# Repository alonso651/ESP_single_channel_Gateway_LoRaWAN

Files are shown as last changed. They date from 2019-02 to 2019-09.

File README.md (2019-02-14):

Gateway LoRaWAN ESP8266 de un solo canal
========================================
Febrero de 2019 

Single Channel Gateway LoRaWAN
------------------------------
Es un Gateway LoRaWAN de un único canal.

Cuenta con dos modos de funcionamiento:
1. Normal: Un solo canal (0-7) y un SF (SF7-SF12).
2. CAD: Un solo canal (0-7) y todos los SF de SF7 a SF12 (Más versátil).

En la configuración actual se utilizó la primer sub banda (sub banda 1) de la banda 
de frecuencias ISM US915 MHz. 

Sub banda 1 (903.9 - 905.3 MHz): 

	· Canal 0 - 903.9 MHz
	· Canal 1 - 904.1 MHz
	· Canal 2 - 904.3 MHz
	· Canal 3 - 904.5 MHz
	· Canal 4 - 904.7 MHz
	· Canal 5 - 904.9 MHz
	· Canal 6 - 905.1 MHz
	· Canal 7 - 905.3 MHz

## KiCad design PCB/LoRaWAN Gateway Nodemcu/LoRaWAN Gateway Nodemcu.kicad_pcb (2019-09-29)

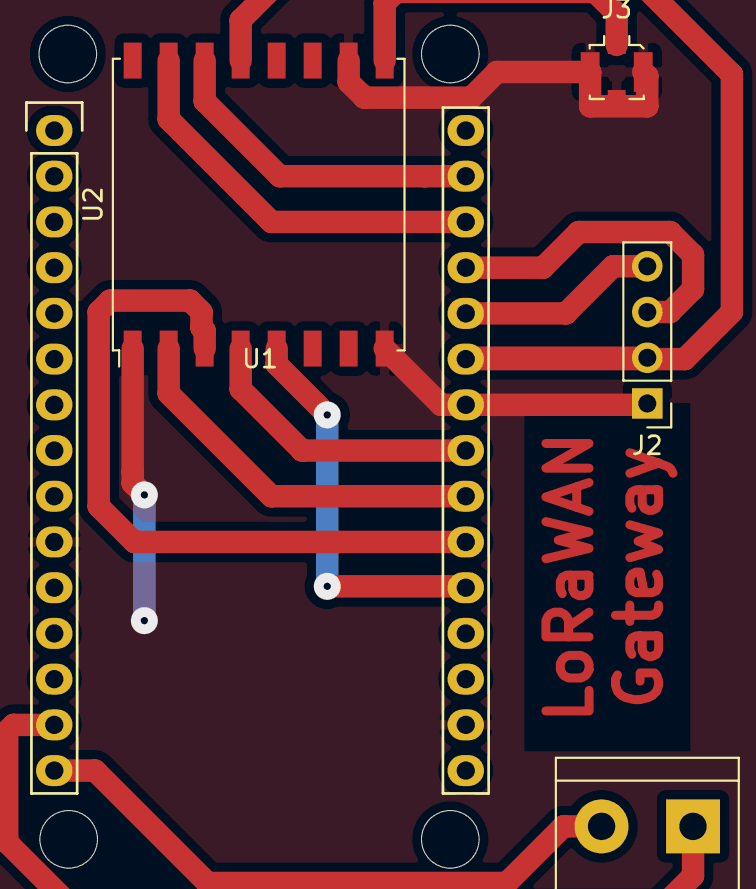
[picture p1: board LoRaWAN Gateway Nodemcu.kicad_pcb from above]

Board: 2 copper layers, 5 parts (0 on the bottom side), 13 nets.

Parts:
J1: 5V in; TerminalBlock_bornier-2_P5.08mm
J2: Display Oled I2C; PinHeader_1x04_P2.54mm_Vertical
J3: Antena; U.FL_Molex_MCRF_73412-0110_Vertical
U1: NodeMCU Amica R2; NodeMCU_Amica_R2
U2: RFM95W; HOPERF_RFM9XW_SMD

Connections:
/3v3: J2.2, U1.11, U1.16, U1.25, U2.13
/ANT: J3.1, U2.9
/DIO0: U1.29, U2.14
/DIO1: U1.28, U2.15
/GND: J2.1, J3.2, U1.10, U1.17, U1.24, U2.1, U2.8, U2.10
/GNDin: J1.1, U1.14
/MISO: U1.22, U2.2
/MOSI: U1.21, U2.3
/NSS: U1.20, U2.5
/SCK: U1.23, U2.4
/SCL: J2.3, U1.27
/SDA: J2.4, U1.26
/Vin: J1.2, U1.15

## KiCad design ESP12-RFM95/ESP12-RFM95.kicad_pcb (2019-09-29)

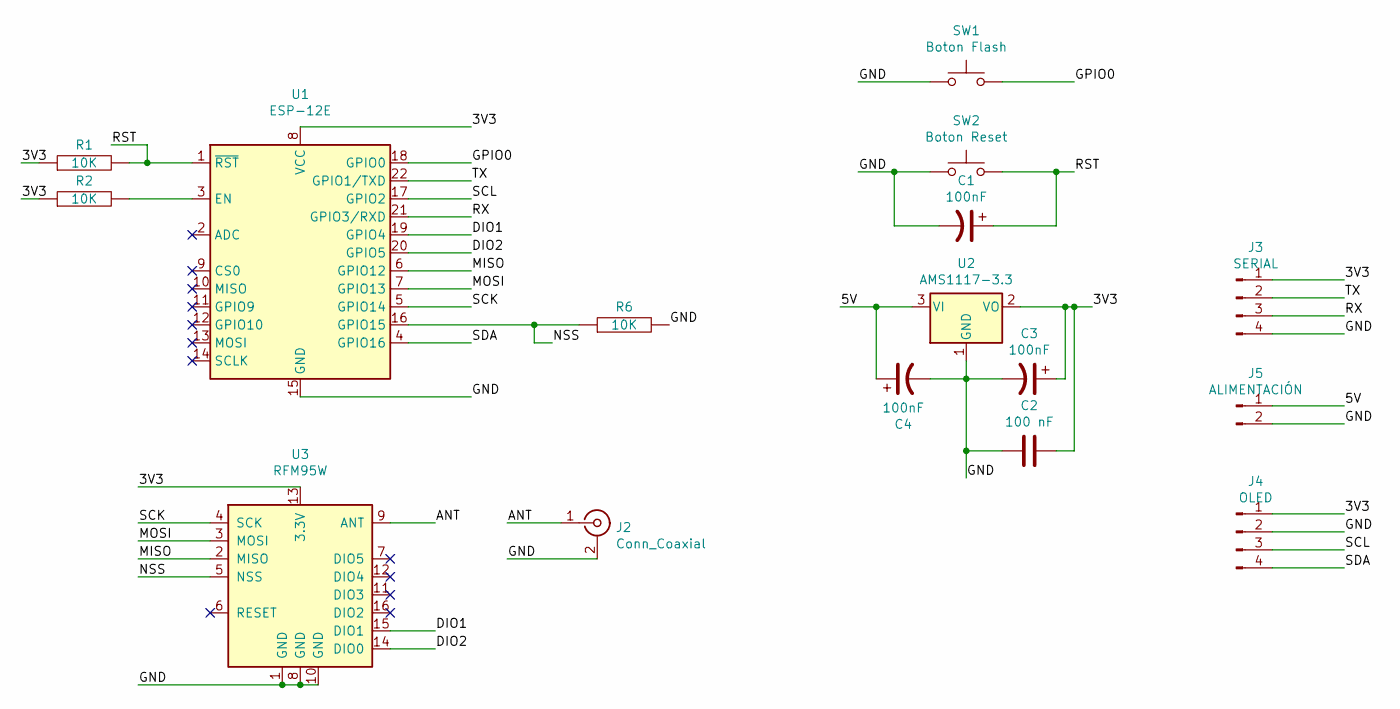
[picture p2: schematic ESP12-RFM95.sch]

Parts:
C1, C3, C4: 100nF; CP_Radial_D5.0mm_P2.50mm
C2: 100 nF; C_Disc_D3.0mm_W2.0mm_P2.50mm
J2: Conn_Coaxial; SMA_Amphenol_901-144_Vertical
J3: SERIAL; PinHeader_1x04_P2.54mm_Horizontal
J4: OLED; I2C_SSD1306
J5: ALIMENTACIÓN; PinHeader_1x02_P2.54mm_Vertical
R1, R2, R6: 10K; R_Axial_DIN0207_L6.3mm_D2.5mm_P5.08mm_Vertical
SW1: Boton Flash; SW_DIP_SPSTx01_Slide_6.7x4.1mm_W6.73mm_P2.54mm_LowProfile_J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
SW2: Boton Reset; SW_DIP_SPSTx01_Slide_6.7x4.1mm_W6.73mm_P2.54mm_LowProfile_J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
U1: ESP-12E; ESP-12E_2
U2: AMS1117-3.3; SOT-223-3_TabPin2
U3: RFM95W; HOPERF_RFM9XW_SMD

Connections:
/3V3: C2.1, C3.1, J3.1, J4.1, R1.1, R2.1, U1.8 (VCC), U2.2 (VO), U3.13 (3.3V); also elsewhere on the board
/5V: C4.1, J5.1, U2.3 (VI)
/ANT: J2.1 (In), U3.9 (ANT)
/DIO1: U1.19 (GPIO4), U3.15 (DIO1)
/DIO2: U1.20 (GPIO5), U3.14 (DIO0)
/GND: C1.2, C2.2, C3.2, C4.2, J2.2 (Ext), J3.4, J4.2, J5.2, R6.2, SW1.1, SW2.1, U1.15 (GND), U2.1 (GND), U3.1 (GND), U3.8 (GND), U3.10 (GND); also elsewhere on the board
/GPIO0: SW1.2, U1.18 (GPIO0)
/MISO: U1.6 (GPIO12), U3.2 (MISO)
/MOSI: U1.7 (GPIO13), U3.3 (MOSI)
/NSS: R6.1, U1.16 (GPIO15), U3.5 (NSS)
/RST: C1.1, R1.2, SW2.2, U1.1 (~RST)
/RX: J3.3, U1.21 (GPIO3/RXD)
/SCK: U1.5 (GPIO14), U3.4 (SCK)
/SCL: J4.3, U1.17 (GPIO2); also elsewhere on the board
/SDA: J4.4, U1.4 (GPIO16); also elsewhere on the board
/TX: J3.2, U1.22 (GPIO1/TXD)
unnamed: R2.2, U1.3 (EN)

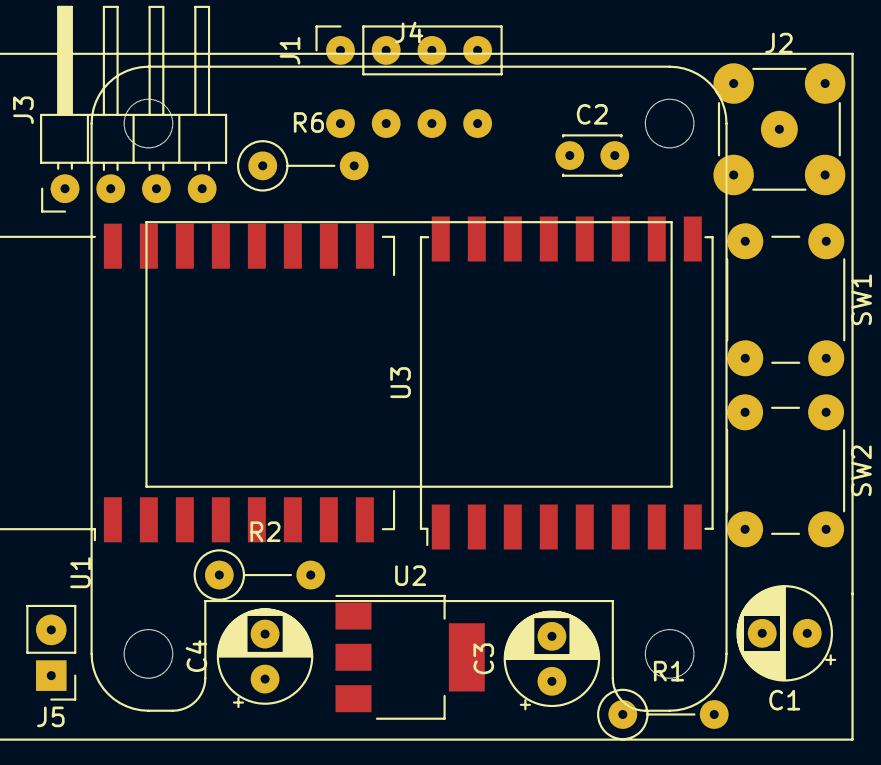
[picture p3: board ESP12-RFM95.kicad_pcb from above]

Board: 2 copper layers, 17 parts (0 on the bottom side), 17 nets.

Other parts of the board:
J1: I2C; PinSocket_1x04_P2.54mm_Vertical

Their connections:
/3V3: J1.1; also elsewhere on the board
/GND: J1.2; also elsewhere on the board
/SCL: J1.3; also elsewhere on the board
/SDA: J1.4; also elsewhere on the board

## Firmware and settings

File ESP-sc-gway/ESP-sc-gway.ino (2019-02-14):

// 1-channel LoRa Gateway for ESP8266 jjjjjjjj
// Copyright (c) 2016, 2017, 2018 Maarten Westenberg version for ESP8266
// Version 5.3.3
// Date: 2018-08-25
// Author: Maarten Westenberg (mw12554@hotmail.com)
//
// Based on work done by Thomas Telkamp for Raspberry PI 1-ch gateway and many others.
//
// All rights reserved. This program and the accompanying materials
// are made available under the terms of the MIT License
// which accompanies this distribution, and is available at
// https://opensource.org/licenses/mit-license.php
//
// NO WARRANTY OF ANY KIND IS PROVIDED
//
// The protocols and specifications used for this 1ch gateway: 
// 1. LoRA Specification version V1.0 and V1.1 for Gateway-Node communication
//	
// 2. Semtech Basic communication protocol between Lora gateway and server version 3.0.0
//	https://github.com/Lora-net/packet_forwarder/blob/master/PROTOCOL.TXT
//
// Notes: 
// - Once call gethostbyname() to get IP for services, after that only use IP
//	 addresses (too many gethost name makes the ESP unstable)
// - Only call yield() in main stream (not for background NTP sync). 
//
// ----------------------------------------------------------------------------------------

#include "ESP-sc-gway.h"						// This file contains configuration of GWay

#if defined (ARDUINO_ARCH_ESP32) || defined(ESP32)
#define ESP32_ARCH 1
#endif

#include <Esp.h>								// ESP8266 specific IDE functions
#include <string.h>
#include <stdio.h>
#include <sys/types.h>
#include <unistd.h>
#include <fcntl.h>
#include <cstdlib>
#include <sys/time.h>
#include <cstring>
#include <string>								// C++ specific string functions

#include <SPI.h>								// For the RFM95 bus
#include <TimeLib.h>							// http://playground.arduino.cc/code/time
#include <DNSServer.h>							// Local DNSserver
#include <ArduinoJson.h>
#include <FS.h>									// ESP8266 Specific
#include <WiFiUdp.h>
#include <pins_arduino.h>
#include <gBase64.h>							// https://github.com/adamvr/arduino-base64 (changed the name)

// Local include files
#include "loraModem.h"
#include "loraFiles.h"
#include "sensor.h"
#include "oLED.h"

extern "C" {
#include "lwip/err.h"
#include "lwip/dns.h"
}

#if WIFIMANAGER==1
#include <WiFiManager.h>						// Library for ESP WiFi config through an AP
#endif

#if (GATEWAYNODE==1) || (_LOCALSERVER==1)
#include "AES-128_V10.h"
#endif


// ----------- Specific ESP32 stuff --------------
#if ESP32_ARCH==1								// IF ESP32

#include "WiFi.h"
#include <WiFiClient.h>
#include <ESPmDNS.h>
#include <SPIFFS.h>
#if A_SERVER==1
#include <ESP32WebServer.h>						// Dedicated Webserver for ESP32
#include <Streaming.h>          				// http://arduiniana.org/libraries/streaming/
#endif
#if A_OTA==1
#include <ESP32httpUpdate.h>					// Not yet available
#include <ArduinoOTA.h>
#endif//OTA

// ----------- Generic ESP8266 stuff --------------
#else

#include <ESP8266WiFi.h>						// Which is specific for ESP8266
#include <ESP8266mDNS.h>
extern "C" {
#include "user_interface.h"
#include "c_types.h"
}
#if A_SERVER==1
#include <ESP8266WebServer.h>
#include <Streaming.h>          				// http://arduiniana.org/libraries/streaming/
#endif //A_SERVER
#if A_OTA==1
#include <ESP8266httpUpdate.h>
#include <ArduinoOTA.h>
#endif//OTA

#endif//ESP_ARCH

// ----------- Declaration of vars --------------
uint8_t debug=1;								// Debug level! 0 is no msgs, 1 normal, 2 extensive
uint8_t pdebug=0xFF;							// Allow all atterns (departments)

#if GATEWAYNODE==1
#if _GPS==1
#include <TinyGPS++.h>
TinyGPSPlus gps;
HardwareSerial Serial1(1);
#endif
#endif

// You can switch webserver off if not necessary but probably better to leave it in.
#if A_SERVER==1
#if ESP32_ARCH==1
	ESP32WebServer server(A_SERVERPORT);
#else
	ESP8266WebServer server(A_SERVERPORT);
#endif
#endif
using namespace std;

byte currentMode = 0x81;

bool sx1272 = true;								// Actually we use sx1276/RFM95

uint32_t cp_nb_rx_rcv;							// Number of messages received by gateway
uint32_t cp_nb_rx_ok;							// Number of messages received OK
uint32_t cp_nb_rx_bad;							// Number of messages received bad
uint32_t cp_nb_rx_nocrc;						// Number of messages without CRC
uint32_t cp_up_pkt_fwd;

uint8_t MAC_array[6];

// ----------------------------------------------------------------------------
//
// Configure these values only if necessary!
//
// ----------------------------------------------------------------------------

// Set spreading factor (SF7 - SF12)
sf_t sf 			= _SPREADING;
sf_t sfi 			= _SPREADING;				// Initial value of SF

// Set location, description and other configuration parameters
// Defined in ESP-sc_gway.h
//
float lat			= _LAT;						// Configuration specific info...
float lon			= _LON;
int   alt			= _ALT;
char platform[24]	= _PLATFORM; 				// platform definition
char email[40]		= _EMAIL;    				// used for contact email
char description[64]= _DESCRIPTION;				// used for free form description 

// define servers

IPAddress ntpServer;							// IP address of NTP_TIMESERVER
IPAddress ttnServer;							// IP Address of thethingsnetwork server
IPAddress thingServer;

WiFiUDP Udp;

time_t startTime = 0;							// The time in seconds since 1970 that the server started
												// be aware that UTP time has to succeed for meaningful values.
												// We use this variable since millis() is reset every 50 days...
uint32_t eventTime = 0;							// Timing of _event to change value (or not).
uint32_t sendTime = 0;							// Time that the last message transmitted
uint32_t doneTime = 0;							// Time to expire when CDDONE takes too long
uint32_t statTime = 0;							// last time we sent a stat message to server
uint32_t pulltime = 0;							// last time we sent a pull_data request to server
//uint32_t lastTmst = 0;							// Last activity Timer

#if A_SERVER==1
uint32_t wwwtime = 0;
#endif
#if NTP_INTR==0
uint32_t ntptimer = 0;
#endif

#define TX_BUFF_SIZE  1024						// Upstream buffer to send to MQTT
#define RX_BUFF_SIZE  1024						// Downstream received from MQTT
#define STATUS_SIZE	  512						// Should(!) be enough based on the static text .. was 1024

#if GATEWAYNODE==1
uint16_t frameCount=0;							// We write this to SPIFF file
#endif

// volatile bool inSPI This initial value of mutex is to be free,
// which means that its value is 1 (!)
// 
int mutexSPI = 1;

// ----------------------------------------------------------------------------
// FORWARD DECARATIONS
// These forward declarations are done since other .ino fils are linked by the
// compiler/linker AFTER the main ESP-sc-gway.ino file. 
// And espcesially when calling functions with ICACHE_RAM_ATTR the complier 
// does not want this.
// Solution can also be to pecify less STRICT compile options in Makefile
// ----------------------------------------------------------------------------

void ICACHE_RAM_ATTR Interrupt_0();
void ICACHE_RAM_ATTR Interrupt_1();

int sendPacket(uint8_t *buf, uint8_t length);		// _txRx.ino
void setupWWW();									// _wwwServer.ino
void SerialTime();									// _utils.ino
static void printIP(IPAddress ipa, const char sep, String& response);	// _wwwServer.ino

void init_oLED();									// oLED.ino
void acti_oLED();
void addr_oLED();

void setupOta(char *hostname);
void initLoraModem();								// _loraModem.ino
void cadScanner();
void rxLoraModem();									// _loraModem.ino
void writeRegister(uint8_t addr, uint8_t value);	// _loraModem.ino

void stateMachine();								// _stateMachine.ino

void SerialStat(uint8_t intr);						// _utils.ino

#if MUTEX==1
// Forward declarations
void ICACHE_FLASH_ATTR CreateMutux(int *mutex);
bool ICACHE_FLASH_ATTR GetMutex(int *mutex);
void ICACHE_FLASH_ATTR ReleaseMutex(int *mutex);
#endif

// ----------------------------------------------------------------------------
// DIE is not use actively in the source code anymore.
// It is replaced by a Serial.print command so we know that we have a problem
// somewhere.
// There are at least 3 other ways to restart the ESP. Pick one if you want.
// ----------------------------------------------------------------------------
void die(const char *s)
{
	Serial.println(s);
	if (debug>=2) Serial.flush();

	delay(50);
	// system_restart();						// SDK function
	// ESP.reset();				
	abort();									// Within a second
}

// ----------------------------------------------------------------------------
// gway_failed is a function called by ASSERT in ESP-sc-gway.h
//
// ----------------------------------------------------------------------------
void gway_failed(const char *file, uint16_t line) {
	Serial.print(F("Program failed in file: "));
	Serial.print(file);
	Serial.print(F(", line: "));
	Serial.println(line);
	if (debug>=2) Serial.flush();
}

// ----------------------------------------------------------------------------
// Print leading '0' digits for hours(0) and second(0) when
// printing values less than 10
// ----------------------------------------------------------------------------
void printDigits(unsigned long digits)
{
    // utility function for digital clock display: prints leading 0
    if(digits < 10)
        Serial.print(F("0"));
    Serial.print(digits);
}

// ----------------------------------------------------------------------------
// Print utin8_t values in HEX with leading 0 when necessary
// ----------------------------------------------------------------------------
void printHexDigit(uint8_t digit)
{
    // utility function for printing Hex Values with leading 0
    if(digit < 0x10)
        Serial.print('0');
    Serial.print(digit,HEX);
}


// ----------------------------------------------------------------------------
// Print the current time
// ----------------------------------------------------------------------------
static void printTime() {
	switch (weekday())
	{
		case 1: Serial.print(F("Sunday")); break;
		case 2: Serial.print(F("Monday")); break;
		case 3: Serial.print(F("Tuesday")); break;
		case 4: Serial.print(F("Wednesday")); break;
		case 5: Serial.print(F("Thursday")); break;
		case 6: Serial.print(F("Friday")); break;
		case 7: Serial.print(F("Saturday")); break;
		default: Serial.print(F("ERROR")); break;
	}
	Serial.print(F(" "));
	printDigits(hour());
	Serial.print(F(":"));
	printDigits(minute());
	Serial.print(F(":"));
	printDigits(second());
	return;
}


// ----------------------------------------------------------------------------
// Convert a float to string for printing
// Parameters:
//	f is float value to convert
//	p is precision in decimal digits
//	val is character array for results
// ----------------------------------------------------------------------------
void ftoa(float f, char *val, int p) {
	int j=1;
	int ival, fval;
	char b[7] = { 0x00, 0x00, 0x00, 0x00, 0x00, 0x00, 0x00 };
	
	for (int i=0; i< p; i++) { j= j*10; }

	ival = (int) f;								// Make integer part
	fval = (int) ((f- ival)*j);					// Make fraction. Has same sign as integer part
	if (fval<0) fval = -fval;					// So if it is negative make fraction positive again.
												// sprintf does NOT fit in memory
	if ((f<0) && (ival == 0)) strcat(val, "-");
	strcat(val,itoa(ival,b,10));				// Copy integer part first, base 10, null terminated
	strcat(val,".");							// Copy decimal point
	
	itoa(fval,b,10);							// Copy fraction part base 10
	for (int i=0; i<(p-strlen(b)); i++) {
		strcat(val,"0"); 						// first number of 0 of faction?
	}
	
	// Fraction can be anything from 0 to 10^p , so can have less digits
	strcat(val,b);
}

// ============================================================================
// NTP TIME functions



// ----------------------------------------------------------------------------
// Send the request packet to the NTP server.
//
// ----------------------------------------------------------------------------
int sendNtpRequest(IPAddress timeServerIP) {
	const int NTP_PACKET_SIZE = 48;				// Fixed size of NTP record
	byte packetBuffer[NTP_PACKET_SIZE];

	memset(packetBuffer, 0, NTP_PACKET_SIZE);	// Zeroise the buffer.
	
	packetBuffer[0]  = 0b11100011;   			// LI, Version, Mode
	packetBuffer[1]  = 0;						// Stratum, or type of clock
	packetBuffer[2]  = 6;						// Polling Interval
	packetBuffer[3]  = 0xEC;					// Peer Clock Precision
	// 8 bytes of zero for Root Delay & Root Dispersion
	packetBuffer[12] = 49;
	packetBuffer[13] = 0x4E;
	packetBuffer[14] = 49;
	packetBuffer[15] = 52;	

	
	if (!sendUdp( (IPAddress) timeServerIP, (int) 123, packetBuffer, NTP_PACKET_SIZE)) {
		gwayConfig.ntpErr++;
		gwayConfig.ntpErrTime = now();
		return(0);	
	}
	return(1);
}


// ----------------------------------------------------------------------------
// Get the NTP time from one of the time servers
// Note: As this function is called from SyncINterval in the background
//	make sure we have no blocking calls in this function
// ----------------------------------------------------------------------------
time_t getNtpTime()
{
	gwayConfig.ntps++;
	
    if (!sendNtpRequest(ntpServer))					// Send the request for new time
	{
		if (( debug>=0 ) && ( pdebug & P_MAIN ))
			Serial.println(F("M sendNtpRequest failed"));
		return(0);
	}
	
	const int NTP_PACKET_SIZE = 48;					// Fixed size of NTP record
	byte packetBuffer[NTP_PACKET_SIZE];
	memset(packetBuffer, 0, NTP_PACKET_SIZE);		// Set buffer cntents to zero

    uint32_t beginWait = millis();
	delay(10);
    while (millis() - beginWait < 1500) 
	{
		int size = Udp.parsePacket();
		if ( size >= NTP_PACKET_SIZE ) {
		
			if (Udp.read(packetBuffer, NTP_PACKET_SIZE) < NTP_PACKET_SIZE) {
				break;
			}
			else {
				// Extract seconds portion.
				unsigned long secs;
				secs  = packetBuffer[40] << 24;
				secs |= packetBuffer[41] << 16;
				secs |= packetBuffer[42] <<  8;
				secs |= packetBuffer[43];
				// UTC is 1 TimeZone correction when no daylight saving time
				return(secs - 2208988800UL + NTP_TIMEZONES * SECS_IN_HOUR);
			}
			Udp.flush();	
		}
		delay(100);									// Wait 100 millisecs, allow kernel to act when necessary
    }

	Udp.flush();
	
	// If we are here, we could not read the time from internet
	// So increase the counter
	gwayConfig.ntpErr++;
	gwayConfig.ntpErrTime = now();
#if DUSB>=1
	if (( debug>=0 ) && ( pdebug & P_MAIN )) {
		Serial.println(F("M getNtpTime:: read failed"));
	}
#endif
	return(0); 										// return 0 if unable to get the time
}

// ----------------------------------------------------------------------------
// Set up regular synchronization of NTP server and the local time.
// ----------------------------------------------------------------------------
#if NTP_INTR==1
void setupTime() {
  setSyncProvider(getNtpTime);
  setSyncInterval(_NTP_INTERVAL);
}
#endif


// ============================================================================
// UDP  FUNCTIONS


// ----------------------------------------------------------------------------
// Read DOWN a package from UDP socket, can come from any server
// Messages are received when server responds to gateway requests from LoRa nodes 
// (e.g. JOIN requests etc.) or when server has downstream data.
// We respond only to the server that sent us a message!
// Note: So normally we can forget here about codes that do upstream
// Parameters:
//	Packetsize: size of the buffer to read, as read by loop() calling function
//
// Returns:
//	-1 or false if not read
//	Or number of characters read is success
//
// ----------------------------------------------------------------------------
int readUdp(int packetSize)
{
	uint8_t protocol;
	uint16_t token;
	uint8_t ident; 
	uint8_t buff[32]; 						// General buffer to use for UDP, set to 64
	uint8_t buff_down[RX_BUFF_SIZE];		// Buffer for downstream

//	if ((WiFi.status() != WL_CONNECTED) &&& (WlanConnect(10) < 0)) {
	if (WlanConnect(10) < 0) {
#if DUSB>=1
			Serial.print(F("readdUdp: ERROR connecting to WLAN"));
			if (debug>=2) Serial.flush();
#endif
			Udp.flush();
			yield();
			return(-1);
	}

	yield();
	
	if (packetSize > RX_BUFF_SIZE) {
#if DUSB>=1
		Serial.print(F("readUDP:: ERROR package of size: "));
		Serial.println(packetSize);
#endif
		Udp.flush();
		return(-1);
	}
  
	// We assume here that we know the originator of the message
	// In practice however this can be any sender!
	if (Udp.read(buff_down, packetSize) < packetSize) {
#if DUSB>=1
		Serial.println(F("A readUsb:: Reading less chars"));
		return(-1);
#endif
	}

	// Remote Address should be known
	IPAddress remoteIpNo = Udp.remoteIP();

	// Remote port is either of the remote TTN server or from NTP server (=123)
	unsigned int remotePortNo = Udp.remotePort();

	if (remotePortNo == 123) {
		// This is an NTP message arriving
#if DUSB>=1
		if ( debug>=0 ) {
			Serial.println(F("A readUdp:: NTP msg rcvd"));
		}
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
void loop ()
{
	uint32_t uSeconds;									// micro seconds
	int packetSize;
	uint32_t nowSeconds = now();
	
	// check for event value, which means that an interrupt has arrived.
	// In this case we handle the interrupt ( e.g. message received)
	// in userspace in loop().
	//
	stateMachine();									// do the state machine
	
	// After a quiet period, make sure we reinit the modem and state machine.
	// The interval is in seconds (about 15 seconds) as this re-init
	// is a heavy operation. 
	// SO it will kick in if there are not many messages for the gateway.
	// Note: Be careful that it does not happen too often in normal operation.
	//
	if ( ((nowSeconds - statr[0].tmst) > _MSG_INTERVAL ) &&
		(msgTime <= statr[0].tmst) ) 
	{
#if DUSB>=1
		if (( debug>=1 ) && ( pdebug & P_MAIN )) {
			Serial.print("M REINIT:: ");
			Serial.print( _MSG_INTERVAL );
			Serial.print(F(" "));
			SerialStat(0);
		}
#endif

		// startReceiver() ??
		if ((_cad) || (_hop)) {
			_state = S_SCAN;
			sf = SF7;
			cadScanner();
		}
		else {
			_state = S_RX;
			rxLoraModem();
		}
		writeRegister(REG_IRQ_FLAGS_MASK, (uint8_t) 0x00);
		writeRegister(REG_IRQ_FLAGS, (uint8_t) 0xFF);			// Reset all interrupt flags
		msgTime = nowSeconds;
	}

#if A_SERVER==1
	// Handle the Web server part of this sketch. Mainly used for administration 
	// and monitoring of the node. This function is important so it is called at the
	// start of the loop() function.
	yield();
	server.handleClient();
#endif

#if A_OTA==1
	// Perform Over the Air (OTA) update if enabled and requested by user.
	// It is important to put this function early in loop() as it is
	// not called frequently but it should always run when called.
	//
	yield();
	ArduinoOTA.handle();
#endif

	// I event is set, we know that we have a (soft) interrupt.
	// After all necessary web/OTA services are scanned, we will
	// reloop here for timing purposes. 
	// Do as less yield() as possible.
	// XXX 180326
	if (_event == 1) {
		return;
	}
	else yield();

	
	// If we are not connected, try to connect.
	// We will not read Udp in this loop cycle then
	if (WlanConnect(1) < 0) {
#if DUSB>=1
		if (( debug >= 0 ) && ( pdebug & P_MAIN ))
			Serial.println(F("M ERROR reconnect WLAN"));
#endif
		yield();
		return;										// Exit loop if no WLAN connected
	}
	
	// So if we are connected 
	// Receive UDP PUSH_ACK messages from server. (*2, par. 3.3)
	// This is important since the TTN broker will return confirmation
	// messages on UDP for every message sent by the gateway. So we have to consume them.
	// As we do not know when the server will respond, we test in every loop.
	//
	else {
		while( (packetSize = Udp.parsePacket()) > 0) {
#if DUSB>=2
			Serial.println(F("loop:: readUdp calling"));
#endif
			// DOWNSTREAM
			// Packet may be PKT_PUSH_ACK (0x01), PKT_PULL_ACK (0x03) or PKT_PULL_RESP (0x04)
			// This command is found in byte 4 (buffer[3])
			if (readUdp(packetSize) <= 0) {
#if DUSB>=1
				if (( debug>0 ) && ( pdebug & P_MAIN ))
					Serial.println(F("M readUDP error"));
#endif
				break;
			}
			// Now we know we succesfully received message from host
			else {
				//_event=1;								// Could be done double if more messages received
			}
		}
	}
	
	yield();					// XXX 26/12/2017

	// stat PUSH_DATA message (*2, par. 4)
	//	

    if ((nowSeconds - statTime) >= _STAT_INTERVAL) {	// Wake up every xx seconds
#if DUSB>=1
		if (( debug>=1 ) && ( pdebug & P_MAIN )) {
			Serial.print(F("M STAT:: ..."));
			Serial.flush();
		}
#endif
        sendstat();										// Show the status message and send to server
#if DUSB>=1
		if (( debug>=1 ) && ( pdebug & P_MAIN )) {
			Serial.println(F(" done"));
			if (debug>=2) Serial.flush();
		}
#endif	

		// If the gateway behaves like a node, we do from time to time
		// send a node message to the backend server.
		// The Gateway nod emessage has nothing to do with the STAT_INTERVAL
		// message but we schedule it in the same frequency.
		//
#if GATEWAYNODE==1
		if (gwayConfig.isNode) {
			// Give way to internal some Admin if necessary
			yield();
			
			// If the 1ch gateway is a sensor itself, send the sensor values
			// could be battery but also other status info or sensor info
		
			if (sensorPacket() < 0) {
#if DUSB>=1
				Serial.println(F("sensorPacket: Error"));
#endif
			}
		}
#endif
		statTime = nowSeconds;
    }
	
	yield();

	
	// send PULL_DATA message (*2, par. 4)
	//
	nowSeconds = now();
    if ((nowSeconds - pulltime) >= _PULL_INTERVAL) {	// Wake up every xx seconds
#if DUSB>=1
		if (( debug>=2) && ( pdebug & P_MAIN )) {
			Serial.println(F("M PULL"));
			if (debug>=1) Serial.flush();
		}
#endif
        pullData();										// Send PULL_DATA message to server
		startReceiver();
	
		pulltime = nowSeconds;
    }

	
	// If we do our own NTP handling (advisable)
	// We do not use the timer interrupt but use the timing
	// of the loop() itself which is better for SPI
#if NTP_INTR==0
	// Set the time in a manual way. Do not use setSyncProvider
	// as this function may collide with SPI and other interrupts
	yield();											// 26/12/2017
	nowSeconds = now();
	if (nowSeconds - ntptimer >= _NTP_INTERVAL) {
		yield();
		time_t newTime;
		newTime = (time_t)getNtpTime();
		if (newTime != 0) setTime(newTime);
		ntptimer = nowSeconds;
	}
#endif
	

}//loop

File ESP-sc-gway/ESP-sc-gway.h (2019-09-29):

// 1-channel LoRa Gateway for ESP8266
// Copyright (c) 2016, 2017, 2018 Maarten Westenberg version for ESP8266
// Version 5.3.3 H
// Date: 2018-08-25
//
// Based on work done by Thomas Telkamp for Raspberry PI 1ch gateway and many others.
// Contibutions of Dorijan Morelj and Andreas Spies for OLED support.
//
// All rights reserved. This program and the accompanying materials
// are made available under the terms of the MIT License
// which accompanies this distribution, and is available at
// https://opensource.org/licenses/mit-license.php
//
// NO WARRANTY OF ANY KIND IS PROVIDED
//
// Author: Maarten Westenberg (mw12554@hotmail.com)
//
// This file contains a number of compile-time settings that can be set on (=1) or off (=0)
// The disadvantage of compile time is minor compared to the memory gain of not having
// too much code compiled and loaded on your ESP8266.
//
// ----------------------------------------------------------------------------------------

#define VERSION "V.5.3.3.H; 180825a"

// This value of DEBUG determines whether some parts of code get compiled.
// Also this is the initial value of debug parameter. 
// The value can be changed using the admin webserver
// For operational use, set initial DEBUG vaulue 0
#define DEBUG 1

// Debug message will be put on Serial is this one is set.
// If set to 0, not USB Serial prints are done
// Set to 1 it will prinr all user level messages (with correct debug set)
// If set to 2 it will also print interrupt messages (not recommended)
#define DUSB 1

// Define whether we should do a formatting of SPIFFS when starting the gateway
// This is usually a good idea if the webserver is interrupted halfway a writing
// operation.
// Normally, value 0 is a good default.
#define _SPIFF_FORMAT 0

// Define the LoRa Frequncy band that is used. TTN Supported values are 925MHz, 868MHz and 433MHz.
// So supported values are: 433 868 915
#define _LFREQ 915

// The spreading factor is the most important parameter to set for a single channel
// gateway. It specifies the speed/datarate in which the gateway and node communicate.
// As the name says, in principle the single channel gateway listens to one channel/frequency
// and to one spreading factor only.
// This parameters contains the default value of SF, the actual version can be set with
// the webserver and it will be stored in SPIFF
// NOTE: The frequency is set in the loraModem.h file and is default 868.100000 MHz.
#define _SPREADING SF9

// Channel Activity Detection
// This function will scan for valid LoRa headers and determine the Spreading 
// factor accordingly. If set to 1 we will use this function which means the 
// 1-channel gateway will become even more versatile. If set to 0 we will use the
// continuous listen mode.
// Using this function means that we HAVE to use more dio pins on the RFM95/sx1276
// device and also connect enable dio1 to detect this state. 
#define _CAD 1

// Definitions for the admin webserver.
// A_SERVER determines whether or not the admin webpage is included in the sketch.
// Normally, leave it in!
#define A_SERVER 1				// Define local WebServer only if this define is set
#define A_REFRESH 1				// Allow the webserver refresh or not?
#define A_SERVERPORT 80			// Local webserver port (normally 80)
#define A_MAXBUFSIZE 192		// Must be larger than 128, but small enough to work

// Definitions for over the air updates. At the moment we support OTA with IDE
// Make sure that tou have installed Python version 2.7 and have Bonjour in your network.
// Bonjour is included in iTunes (which is free) and OTA is recommended to install 
// the firmware on your router witout having to be really close to the gateway and 
// connect with USB.
#define A_OTA 1

// We support a few pin-out configurations out-of-the-box: HALLARD, COMPRESULT and TTGO ESP32.
// If you use one of these two, just set the parameter to the right value.
// If your pin definitions are different, update the loraModem.h file to reflect these settings.
//	1: HALLARD
//	2: COMRESULT pin out
//	3: ESP32 Wemos pin out
//	4: ESP32 TTGO pinning (should work for 433 and OLED too).
//	5: ESP32 TTGO EU433 MHz with OLED
//	6: Other, define your own in loraModem.h
#define _PIN_OUT 4

// Gather statistics on sensor and Wifi status
// 0= No statistics
// 1= Keep track of messages statistics, number determined by MAX_STAT
// 2= Option 1 + Keep track of messages received PER each SF (default)
// 3= See Option 2, but with extra channel info (Do not use when no Hopping is done)
#define STATISTICS 3

// Maximum number of statistics records gathered. 20 is a good maximum (memory intensive)
#define MAX_STAT 20

// Single channel gateways if they behave strict should only use one frequency 
// channel and one spreading factor. However, the TTN backend replies on RX2 
// timeslot for spreading factors SF9-SF12. 
// Also, the server will respond with SF12 in the RX2 timeslot.
// If the 1ch gateway is working in and for nodes that ONLY transmit and receive on the set
// and agreed frequency and spreading factor. make sure to set STRICT to 1.
// In this case, the frequency and spreading factor for downlink messages is adapted by this
// gateway
// NOTE: If your node has only one frequency enabled and one SF, you must set this to 1
//		in order to receive downlink messages
// NOTE: In all other cases, value 0 works for most gateways with CAD enabled
#define _STRICT_1CH	1

// Allows configuration through WifiManager AP setup. Must be 0 or 1					
#define WIFIMANAGER 0

// Define the name of the accesspoint if the gateway is in accesspoint mode (is
// getting WiFi SSID and password using WiFiManager)
#define AP_NAME "Fibertel WiFi027 2.4GHz"
#define AP_PASSWD "0043591365"

// This section defines whether we use the gateway as a repeater
// For his, we use another output channle as the channel (default==0) we are 
// receiving the messages on.
#define REPEATER 0

// Will we use Mutex or not?
// +SPI is input for SPI, SPO is output for SPI
#define MUTEX 0

// Define if OLED Display is connected to I2C bus. Note that defining an OLED display does not
// impact performance very much, certainly if no OLED is connected. Wrong OLED will not show
// sensible results on display
// OLED==0; No OLED display connected
// OLED==1; 0.9 Oled Screen based on SSD1306
// OLED==2;	1"3 Oled screens for Wemos, 128x64 SH1106
#define OLED 1
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

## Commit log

2019-02-14 ESP Single Channel LoRaWAN
    ESP8266 Single Channel Gateway LoRaWAN SF7-SF12 (CAD mode)
2019-09-29 version 1.1
    [ESP12-RFM95.kicad_pcb, ESP12-RFM95.sch, LoRaWAN Gateway Nodemcu.kicad_pcb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]
